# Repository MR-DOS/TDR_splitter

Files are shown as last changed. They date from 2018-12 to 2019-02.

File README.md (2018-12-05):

# TDR-splitter
----
## Description
Addon to te TDR_avalanche to allow simple measurement of cable reflections.

----
## Overview
This board should be used with the TDR-avalanche to measure cable reflections. The PCB includes trigger generator for the TDR_avalanche, passthrough USB for power supply and resistive splitter to allow connecting a cable and 50 Ohm terminated oscilloscope. The splitter offers 3 ports, 50 Ohm terminated. The signal passes directly over the CABLE port. Insertion loss of the splitter from IN to OUT port is about 20 dB.

----
## Features
### Resistive splitter
Already explained in overview.

### Trigger generator
The trigger generator can output 2, 4 or 8 kHz square wave. 8 kHz is recommended for the TDR_avalanche.

----
## How to use it with TDR_avalanche
Connect TDR_avalanche to the IN port and TRIG\_OUT port. Connect Mini USB B cable as power supply. Connect USB cable to the USB A port and connect the cable to TDR\_avalanche. Connect cable under test to CABLE port. Connect 50 Ohm terminated oscilloscope to the OUT port. Connect second oscilloscope input or trigger to SYNC\_OUT port of TDR\_avalanche. The TDR\_avalanche has to be modified to be usable with this board due to the high insertion loss - you have to remove both the attenuators so that in the emitter there are only the 2x 47R resistors and compensation network and there should be 27 Ohm resistor between output and the emitter network so that it is roughly 50 Ohm terminated (in fact, the termination heavily changes during the avalanche pulse, but this does not matter as long as reflections return after the pulse ends).

----
## How to use it with some other pulse generator
Connect pulser output to IN port, connect cable under test to the CABLE port. Connect oscilloscope to the OUT port. Separate trigger has to be provided by your pulser board.

----
## Images
Oscillogram of an unterminated (open) 50 Ohm cable:
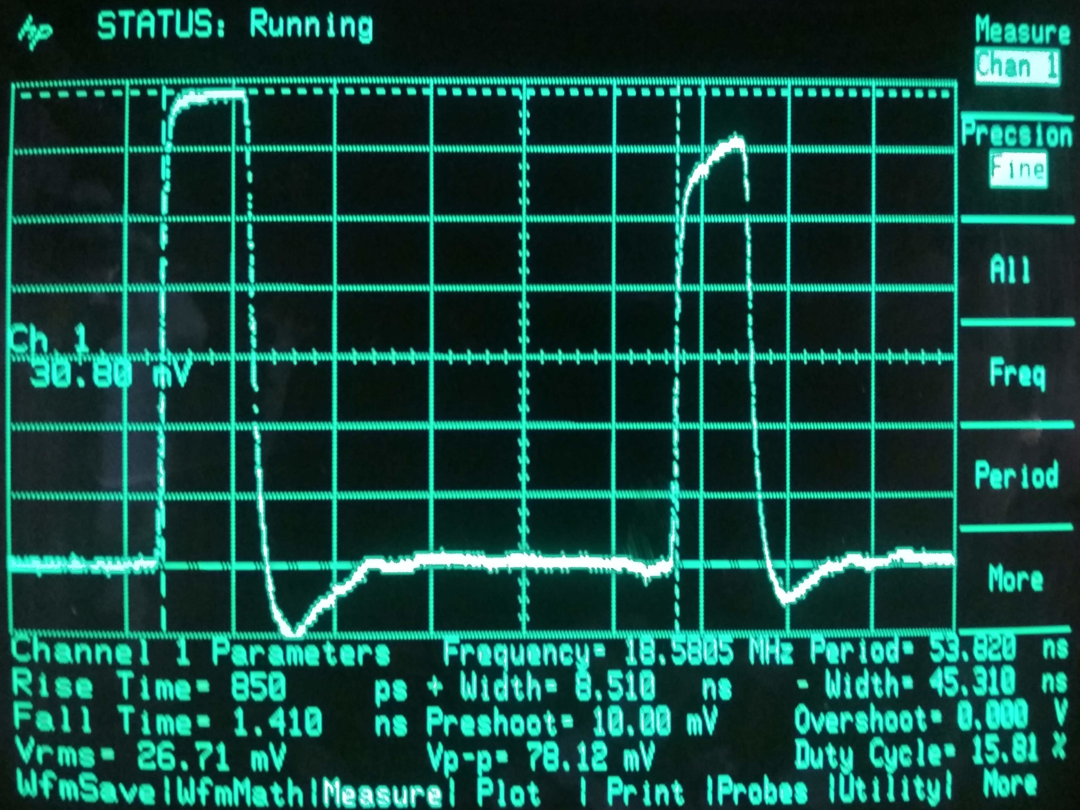
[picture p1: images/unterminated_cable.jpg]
Oscillogram of an unterminated (open) 50 Ohm cable

Oscillogram of an unterminated (open) 50 Ohm cable with defect some 35 cm form the end caused by being heavily pressed using pliers:
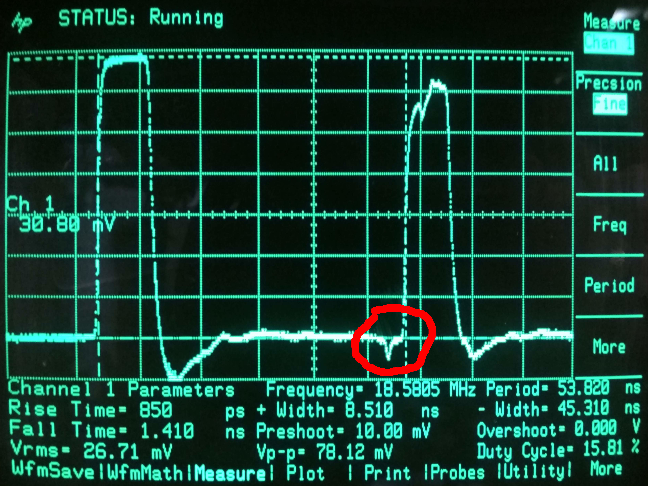
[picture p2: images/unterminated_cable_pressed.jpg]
Oscillogram of an unterminated (open) 50 Ohm cable with defect some 35 cm form the end caused by being heavily pressed using pliers

Closeup of the assembled board with all cables connected (please note that the bad IC footprint is already corrected):
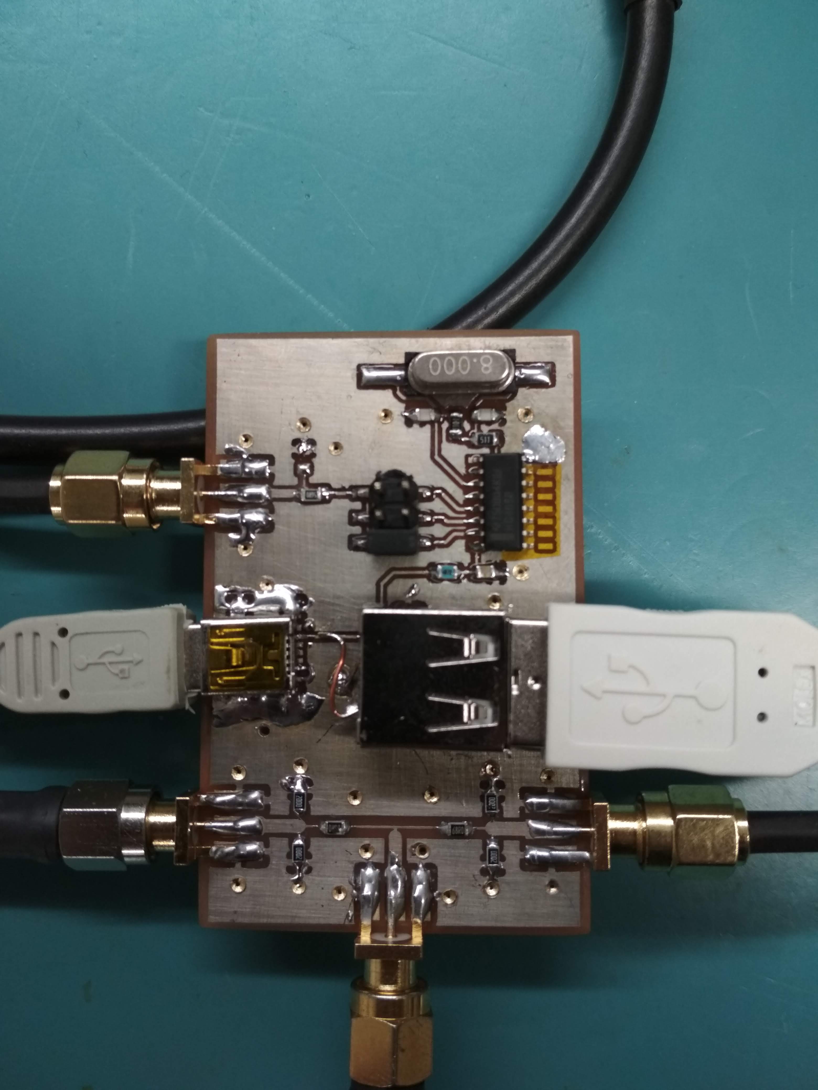
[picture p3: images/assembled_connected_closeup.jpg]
Closeup of the assembled board with all cables connected (please note that the bad IC footprint is already corrected)

Both the TDR\_avalanche and TDR\_splitter connected:
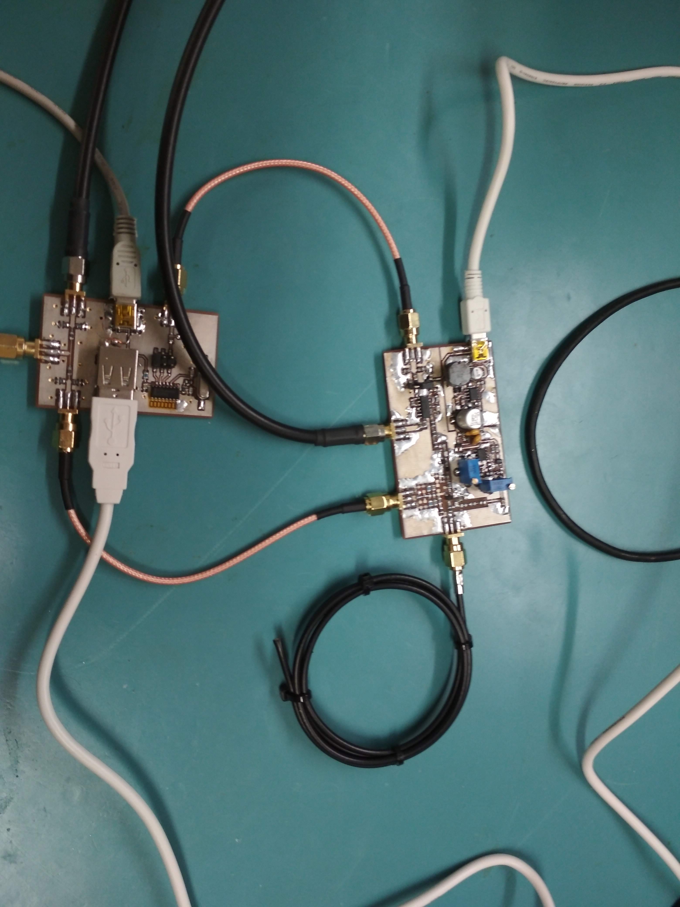
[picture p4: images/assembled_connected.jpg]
Both the TDR\_avalanche and TDR\_splitter connected


----
## References
Sadly, nothing interesting here. I came up with the splitter in my head at 4AM in bed.

[Tweet with photos of the device in use](https://twitter.com/polasek_petr/status/1066757945915072512)

----
## Sidenotes
The PCB uses coplanar waveguide designed for use on standard 1.5 mm FR-4 substrate with 35 um copper (double-sided). It is not very carefully designed and does not give perfect match, but as a prototype, its performance was sufficient. You can modify it for whatever impedance you want, just follow this rule: connect parallel to each of the terminal ports resistor equal to 2x the load impedance, the series resistors should be 4/3x the load impedance and don't forget to update the coplanar waveguide according to the desired impedance.

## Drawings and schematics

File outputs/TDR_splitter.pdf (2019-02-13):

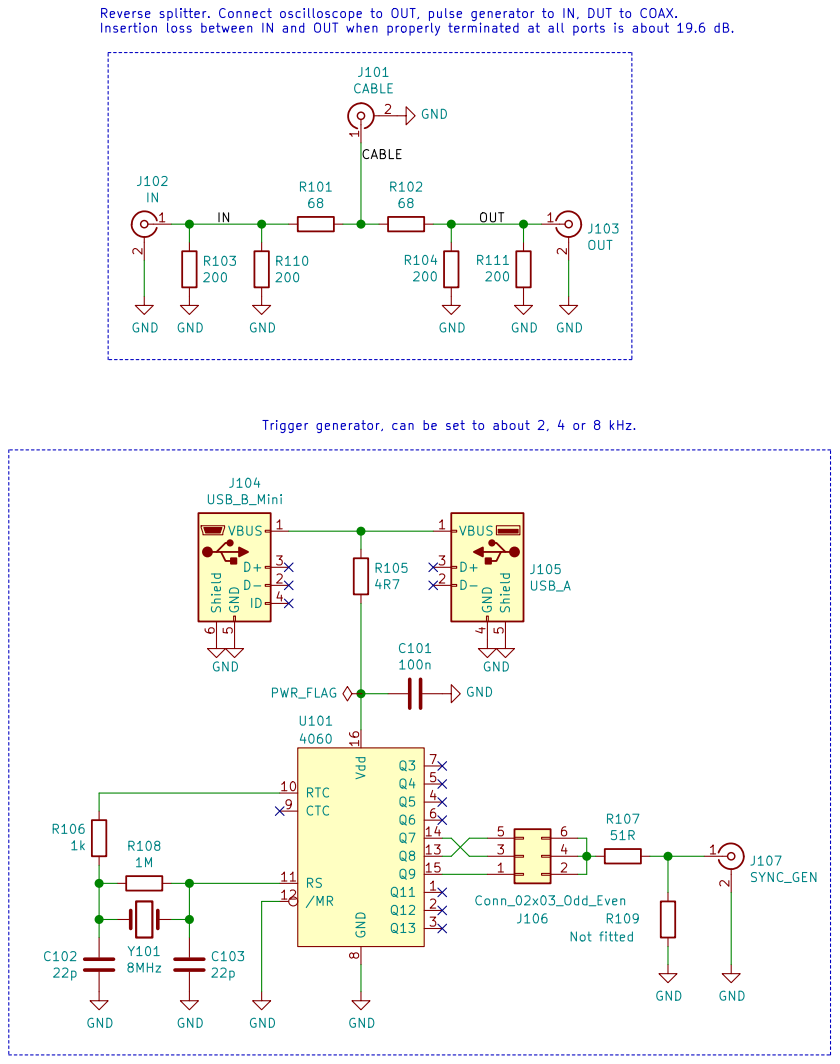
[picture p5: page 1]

Reverse splitter. Connect oscilloscope to OUT, pulse generator to IN, DUT to COAX.
Insertion loss between IN and OUT when properly terminated at all ports is about 19.6 dB.

Trigger generator, can be set to about 2, 4 or 8 kHz.

File: TDR_splitter.sch Sheet: / Petr Polasek Addon to the TDR_avalanche to allow simpler measurement of reflections

Id: 1/1 Title: TDR spliter

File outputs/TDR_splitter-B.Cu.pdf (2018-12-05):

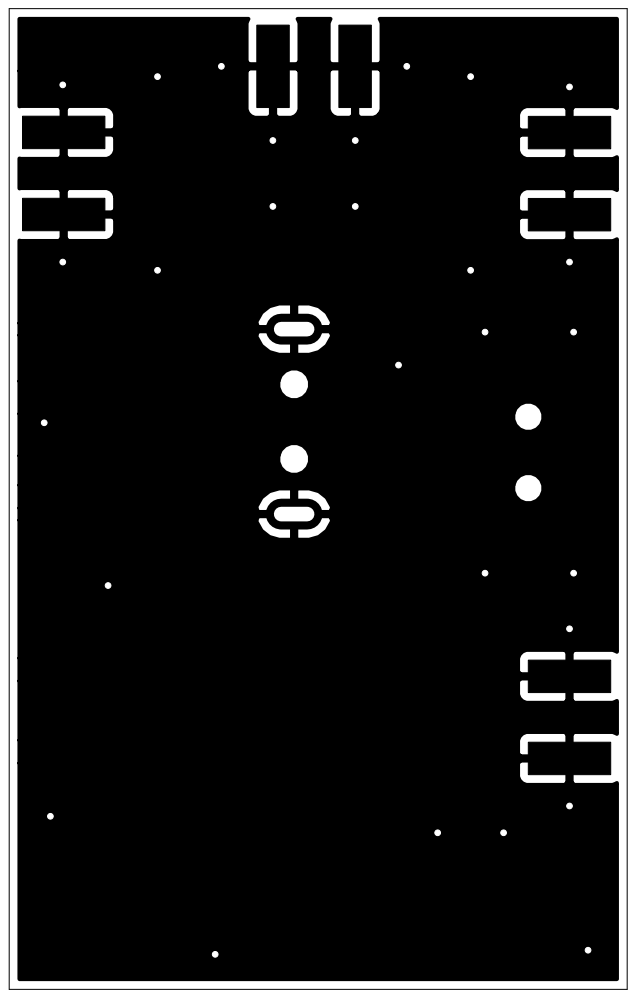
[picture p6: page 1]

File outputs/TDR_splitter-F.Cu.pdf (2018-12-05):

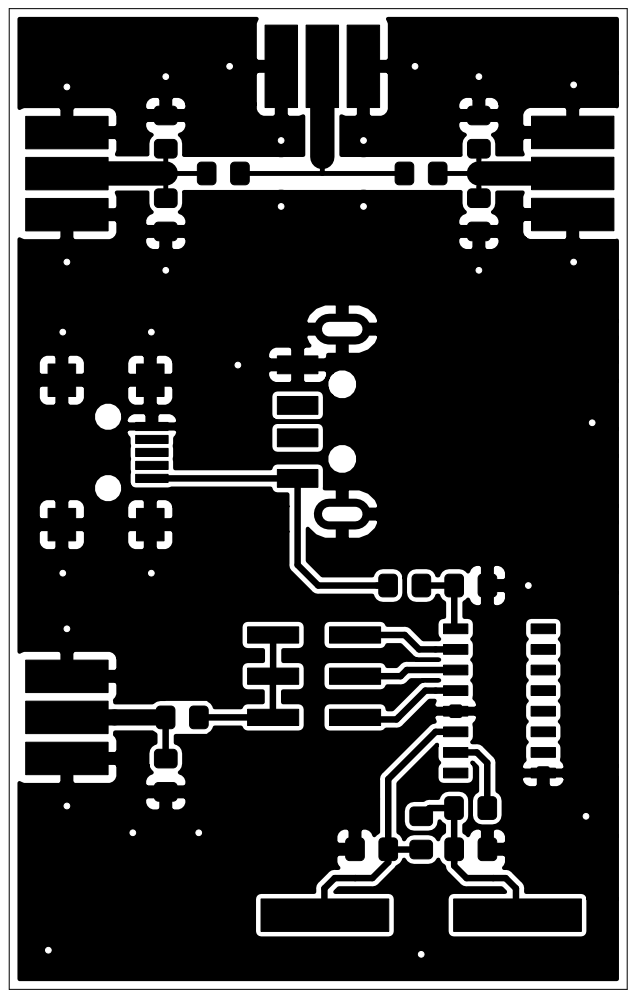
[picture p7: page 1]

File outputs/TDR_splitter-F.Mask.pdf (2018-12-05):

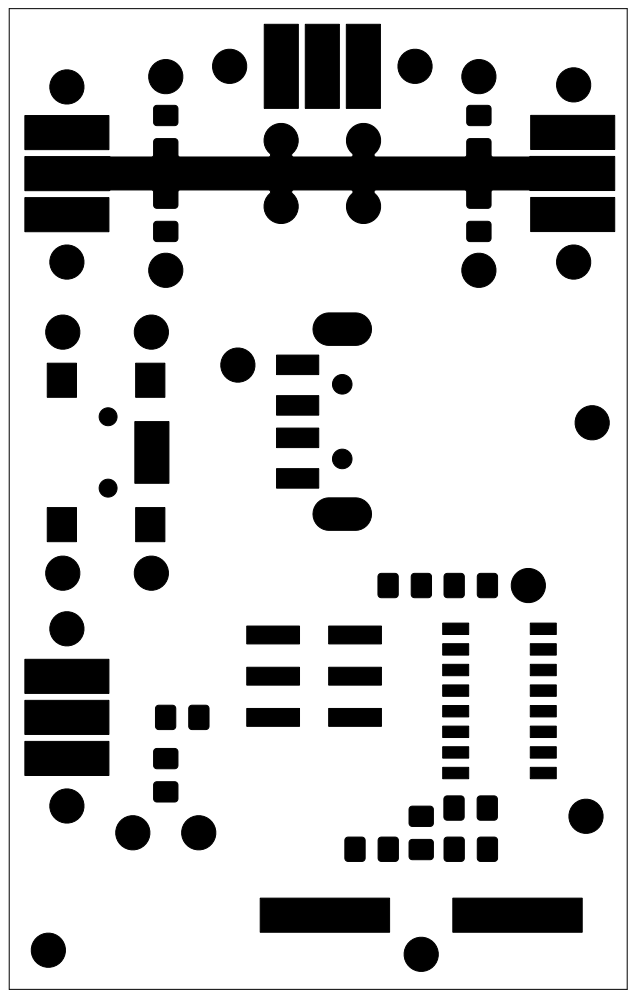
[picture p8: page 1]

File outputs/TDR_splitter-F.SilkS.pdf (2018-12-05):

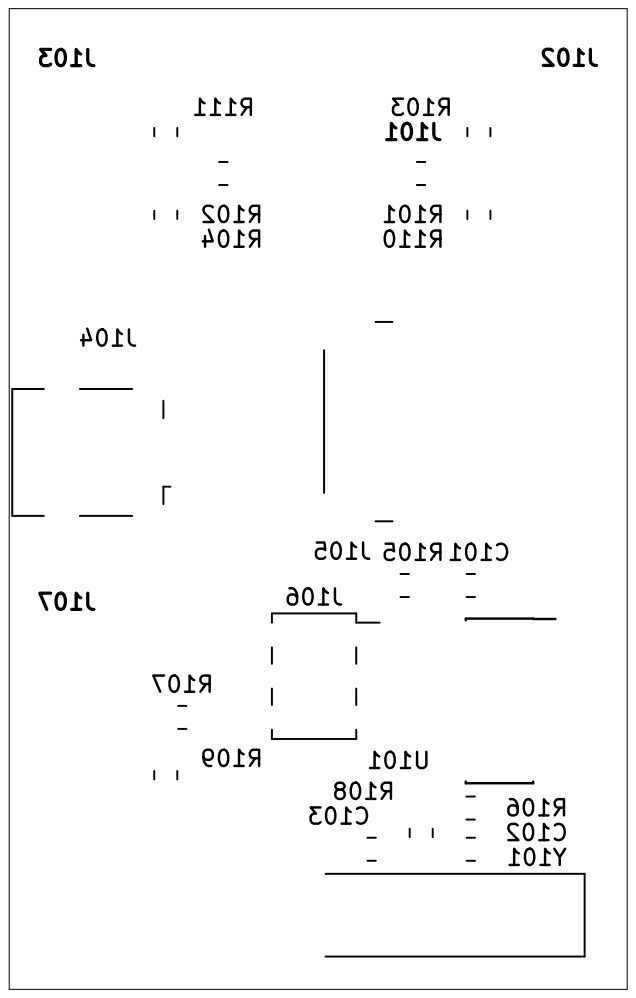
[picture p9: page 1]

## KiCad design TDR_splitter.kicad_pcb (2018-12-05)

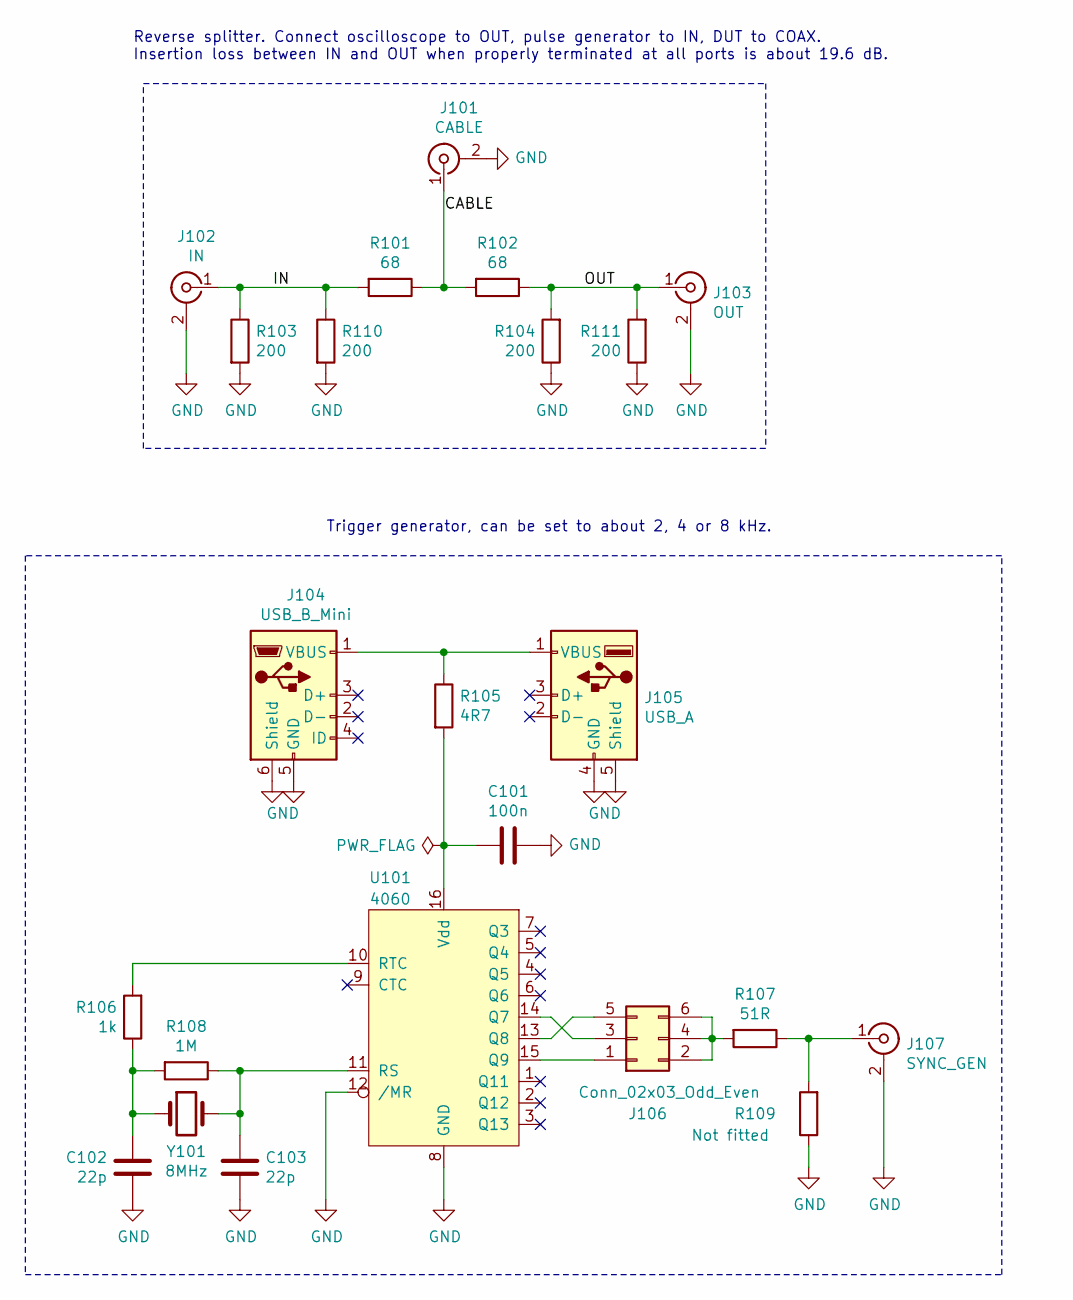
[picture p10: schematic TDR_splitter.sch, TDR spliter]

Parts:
C101: 100n; C_0805_2012Metric_Pad1.15x1.40mm_HandSolder
C102, C103: 22p; C_0805_2012Metric_Pad1.15x1.40mm_HandSolder
J101: CABLE; Molex_SMA_Jack_Edge_Mount_Chinese
J102: IN; Molex_SMA_Jack_Edge_Mount_Chinese
J103: OUT; Molex_SMA_Jack_Edge_Mount_Chinese
J104: USB_B_Mini; USB_Mini-B_Lumberg_2486_01_Horizontal
J105: USB_A; USB_A_CNCTech_1001-011-01101_Horizontal
J106: Conn_02x03_Odd_Even; PinHeader_2x03_P2.54mm_Vertical_SMD
J107: SYNC_GEN; Molex_SMA_Jack_Edge_Mount_Chinese
R101, R102: 68; R_0805_2012Metric_Pad1.15x1.40mm_HandSolder
R103, R104, R110, R111: 200; R_0805_2012Metric_Pad1.15x1.40mm_HandSolder
R105: 4R7; R_0805_2012Metric_Pad1.15x1.40mm_HandSolder
R106: 1k; R_0805_2012Metric_Pad1.15x1.40mm_HandSolder
R107: 51R; R_0805_2012Metric_Pad1.15x1.40mm_HandSolder
R108: 1M; R_0805_2012Metric_Pad1.15x1.40mm_HandSolder
R109: Not fitted; R_0805_2012Metric_Pad1.15x1.40mm_HandSolder
U101: 4060; SOIC-16_3.9x9.9mm_P1.27mm
Y101: 8MHz; Crystal_SMD_HC49-SD_HandSoldering

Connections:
/CABLE: J101.1 (In), R101.1, R102.2
/IN: J102.1 (In), R101.2, R103.1, R110.1
/OUT: J103.1 (In), R102.1, R104.2, R111.2
GND: C101.1, C102.2, C103.2, J101.2 (Ext), J102.2 (Ext), J103.2 (Ext), J104.5 (GND), J104.6 (Shield), J105.4 (GND), J105.5 (Shield), J107.2 (Ext), R103.2, R104.1, R109.1, R110.2, R111.1, U101.8 (GND), U101.12 (/MR)
unnamed: C101.2, R105.2, U101.16 (Vdd)
unnamed: C102.1, R106.1, R108.2, Y101.1
unnamed: C103.1, R108.1, U101.11 (RS), Y101.2
unnamed: J104.1 (VBUS), J105.1 (VBUS), R105.1
unnamed: J106.1, U101.15 (Q9)
unnamed: J106.2, J106.4, J106.6, R107.2
unnamed: J106.3, U101.14 (Q7)
unnamed: J106.5, U101.13 (Q8)
unnamed: J107.1 (In), R107.1, R109.2
unnamed: R106.2, U101.10 (RTC)

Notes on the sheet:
Trigger generator, can be set to about 2, 4 or 8 kHz.
Reverse splitter. Connect oscilloscope to OUT, pulse generator to IN, DUT to COAX. Insertion loss between IN and OUT when properly terminated at all ports is about 19.6 dB.

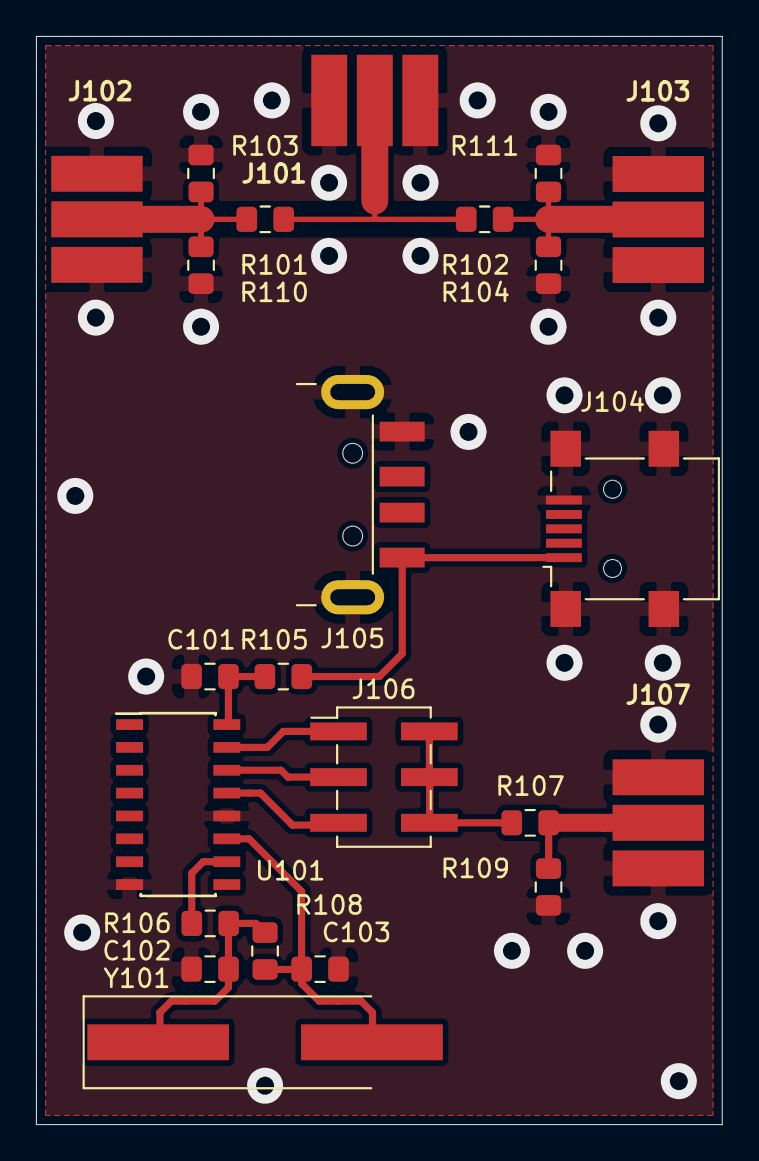
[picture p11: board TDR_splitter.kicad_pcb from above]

Board: 2 copper layers, 38.1 x 60.5 mm, 23 parts (0 on the bottom side), 14 nets.

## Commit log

2018-12-05 Commit of the first tested version along with documentation.
    [TDR_splitter.kicad_pcb, TDR_splitter.sch]
2019-02-13 Added schematic drawing in PDF
